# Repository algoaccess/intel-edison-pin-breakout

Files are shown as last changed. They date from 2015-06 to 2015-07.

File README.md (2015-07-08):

# intel-edison-pin-breakout
Pin breakout of the Intel Edison Hirose connector to through-hole pin headers for prototyping.

##PCB Design software and addons used

1. Eagle 7.3.0: I use Standard but Light should still be able to open/modify the files.
2. Intel Edison library by [Sparkfun](https://github.com/sparkfun/Sparkfun_Blocks_Template) (in repo as Edison.lbr)

##Images

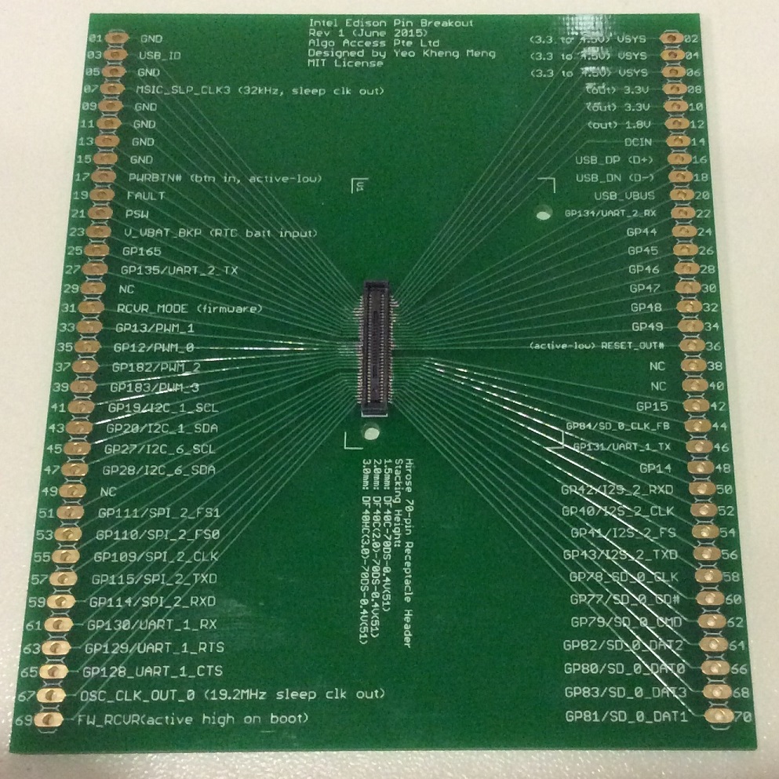
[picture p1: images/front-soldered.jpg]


This has the 1.5mm Hirose connector which I hand soldered.

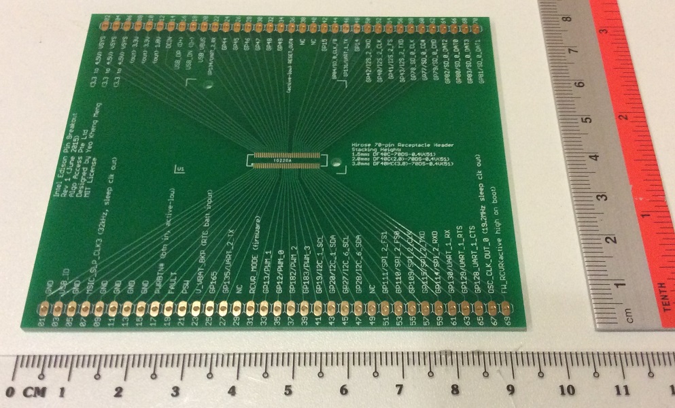
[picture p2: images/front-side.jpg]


The smallest I can make this board to still allow the function of each pin to be silkscreened.

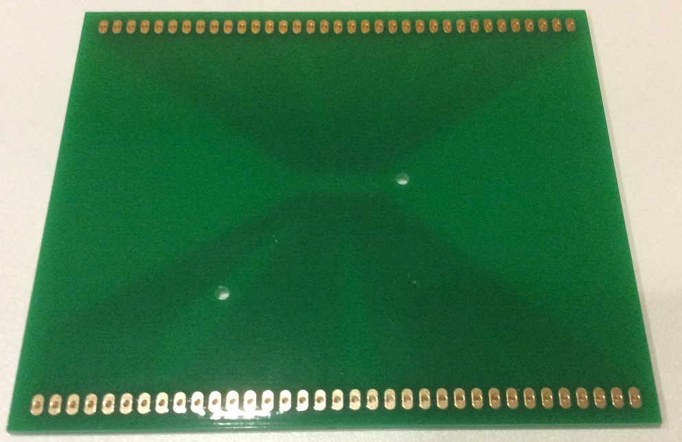
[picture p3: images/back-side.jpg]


2-layer board so you can solder your pin headers on top or below the board.

##Schematic drawings
Images are exported from Eagle at 600dpi.

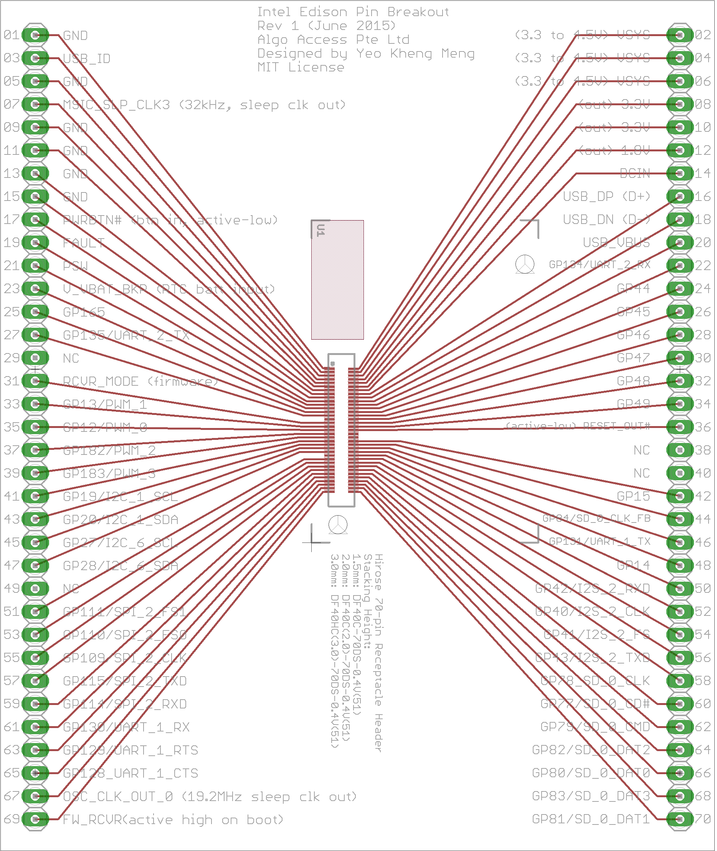
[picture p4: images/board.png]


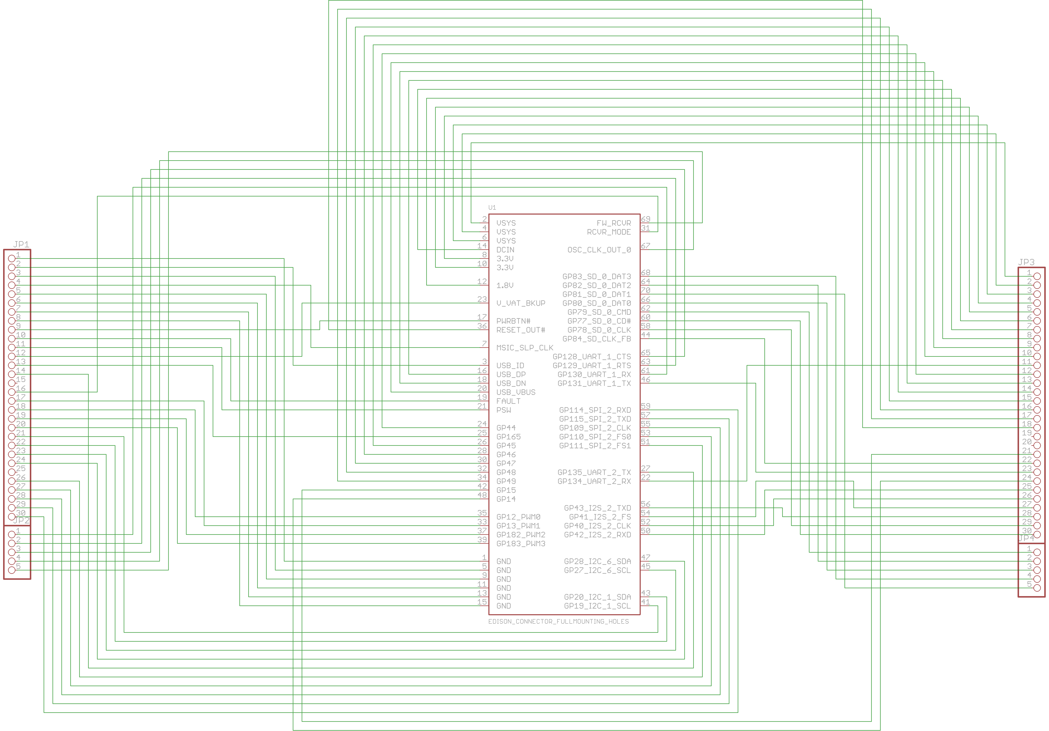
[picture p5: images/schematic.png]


##Parts required

1) Hirose 70-pin DF40 Series Receptacle Connector. Such as the following taken from [Intel's website](http://www.intel.com/support/edison/sb/CS-035260.htm).

| Hirose part number | Stacking height | Digi-key part number | Mouser part number |
|---|---|---|---|
| DF40C-70DS-0.4V(51) | 1.5 mm | H11631TR-ND, [H11631CT-ND](http://www.digikey.sg/product-detail/en/DF40C-70DS-0.4V%2851%29/H11631CT-ND/1969510), H11631DKR-ND | 798-DF40C70DS04V51 |
| DF40C(2.0)-70DS-0.4V(51)  | 2.0 mm | H11908TR-ND, H11908CT-ND, H11908DKR-ND | 798-DF40C2070DS04V51 |
| DF40HC(3.0)-70DS-0.4V(51) | 3.0 mm | n/a | |

I suggest the 1.5mm height header so the Intel Edison can be laid flat on the board without stressing the connectors between them.

2) 2x 35-pin through-hole pin-headers

I used a 36-pin header like [this](http://www.digikey.sg/product-detail/en/PBC36SAAN/S1011E-36-ND/859621) and broke away the last pin.

##PCB fabrication

PCB fabrication is currently done by [Seeedstudio](https://www.seeedstudio.com/service/index.php?r=pcb) based on the following settings. Remember to consult the [order submission guidelines](http://support.seeedstudio.com/knowledgebase/articles/422482-fusion-pcb-order-submission-guidelines) before submitting. Use the provided Gerber generator to produce the Gerber files.

Seeedstudio requires the following gerber files to be zipped up for submission:

1. Top Layer: pcbname.GTL
2. Top Solder Mask: pcbname.GTS
3. Top Silkscreen: pcbname.GTO
4. Bottom Layer: pcbname.GBL
5. Bottom Solder Mask: pcbname.GBS
6. Bottom silkscreen: pcbname.GBO
7. Board Outline:pcbname.GML/GKO
8. Drills: pcbname.TXT
9. Inner Layer: pcbname.GL2(for 4 layer)
10. Inner Layer: pcbname.GL3(for 4 layer)

The zip file has been uploaded to the Releases section.

###My Fabrication Settings: 

1. Layer: 2
2. PCB Dimension: 10cm Max * 10cm Max
3. PCB Thickness: 1.6mm
4. PCB Qty: 10
5. PCB Color: Green
6. Surface Finish: ENIG (due to fine pitch of the pins)
7. Copper weight: 1oz
8. Panalized PCBs: 1
9. Expedited Option: No

##References
1. [Intel Edison Module Hardware guide](http://www.intel.com/support/edison/sb/CS-035274.htm)
2. [Sparkfun Intel Edison layout diagram](https://cdn.sparkfun.com/assets/learn_tutorials/3/2/2/edison-pinout.pdf)

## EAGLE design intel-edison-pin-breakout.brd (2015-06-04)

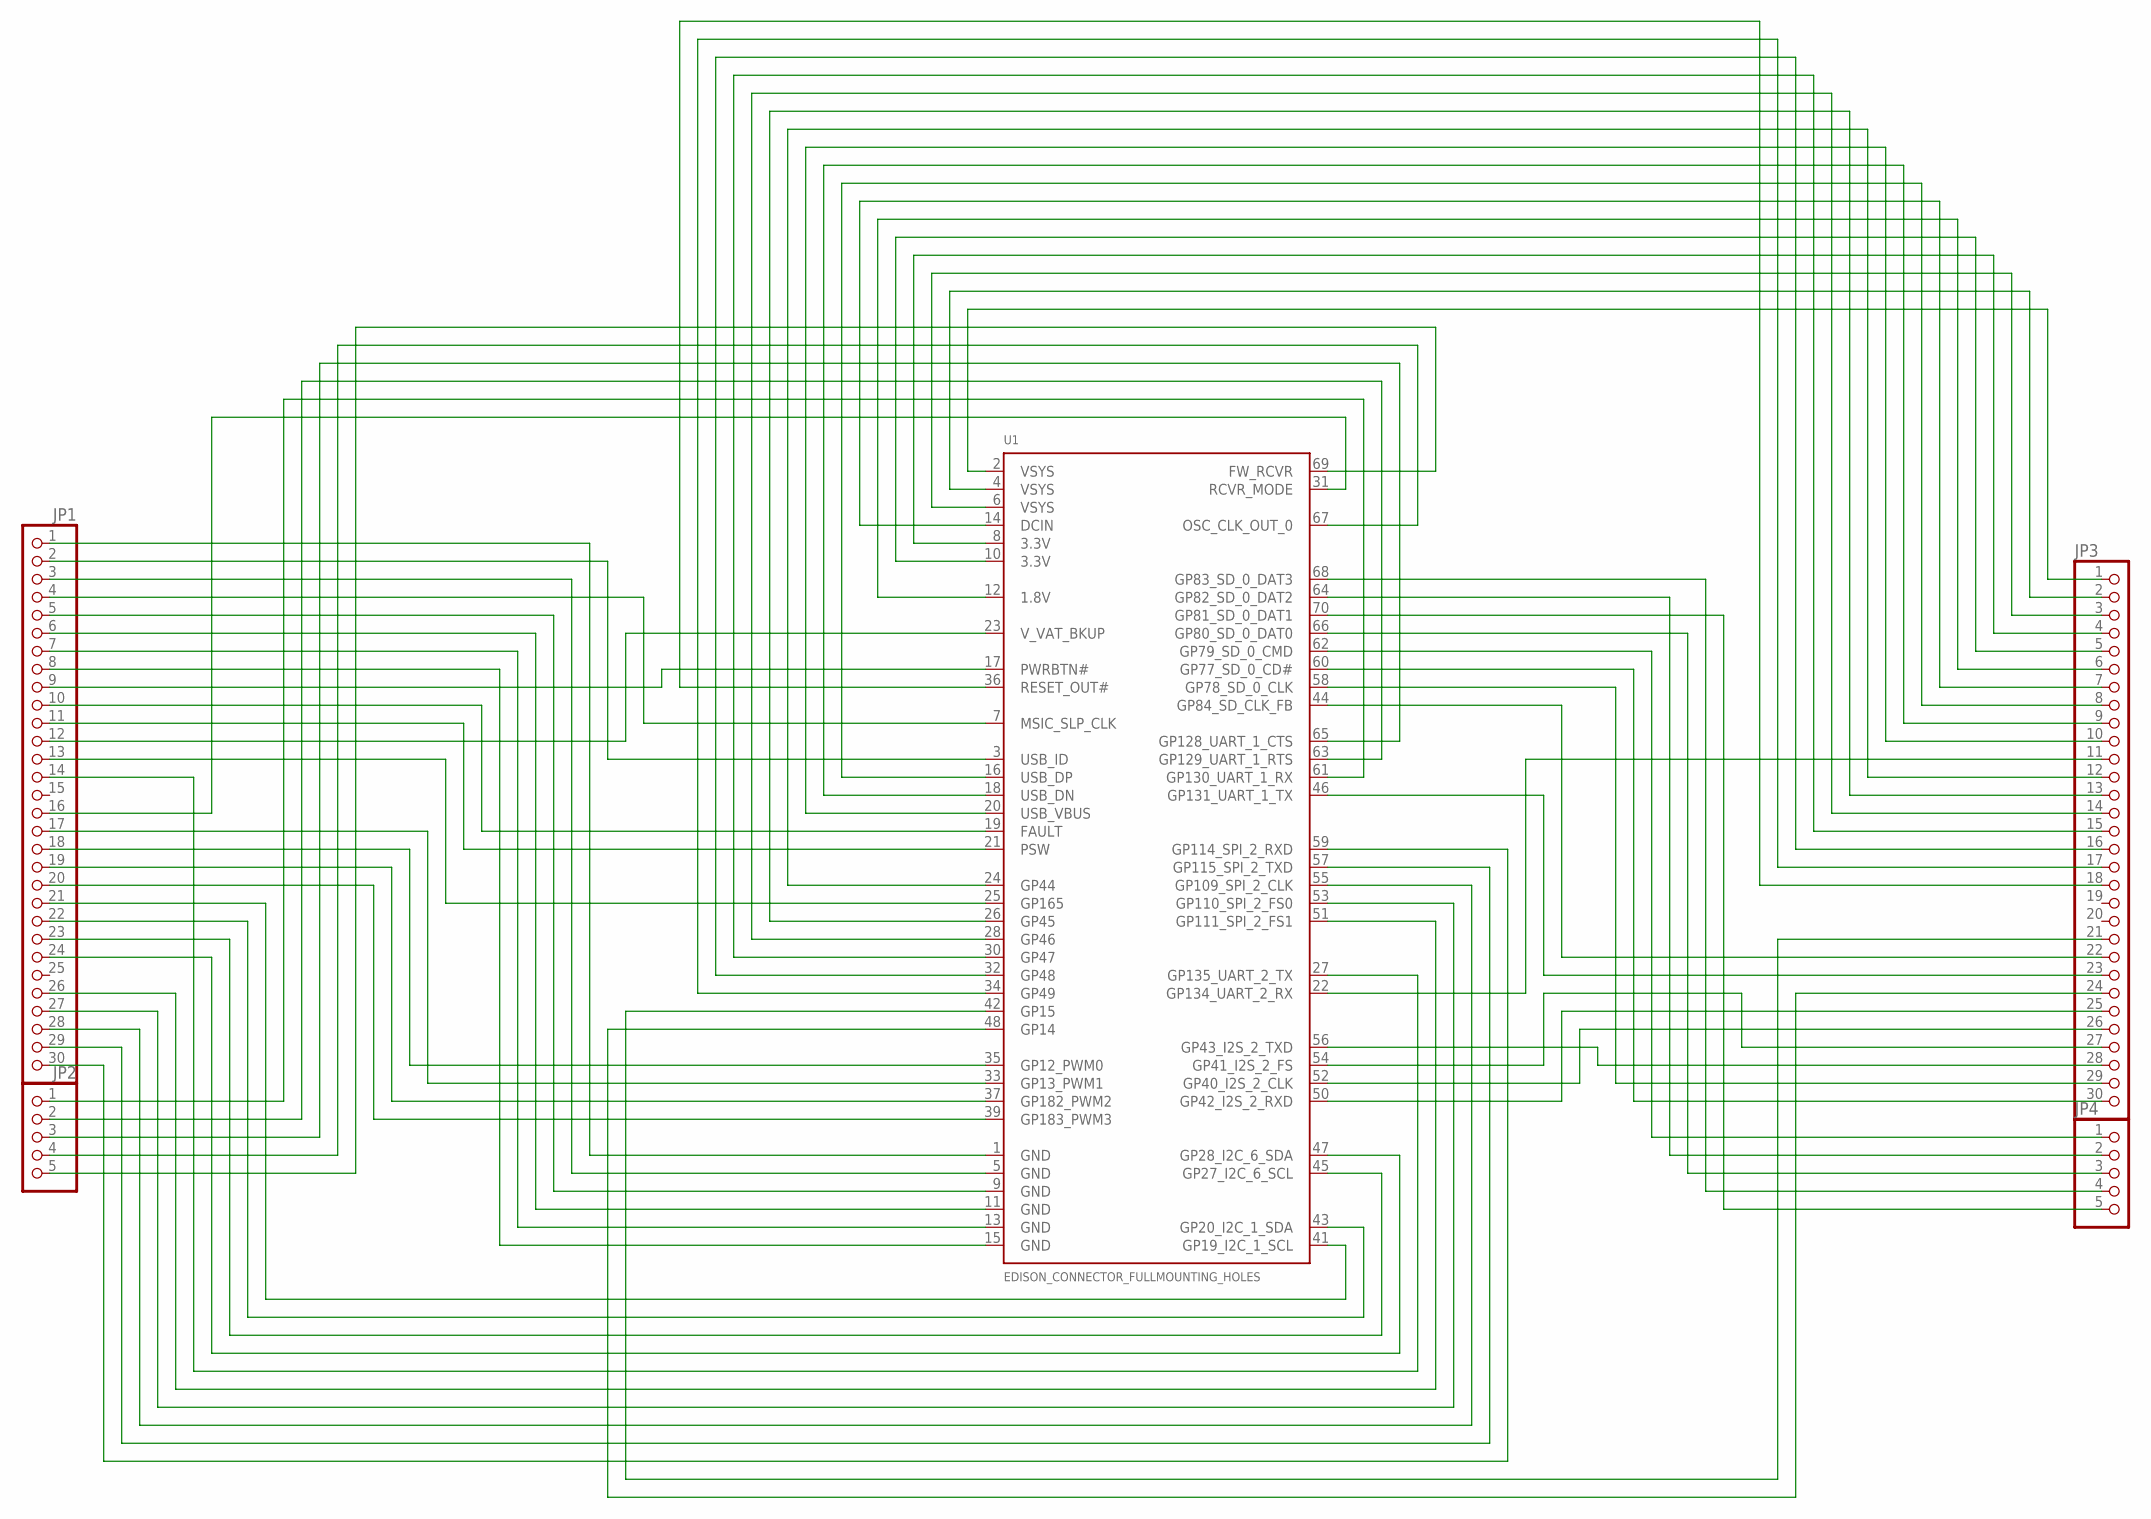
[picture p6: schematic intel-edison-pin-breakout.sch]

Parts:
JP1, JP3: PINHD-1X30; 1X30
JP2, JP4: PINHD-1X5; 1X05
U1: EDISON_CONNECTOR_FULLMOUNTING_HOLES; EDISON_DAUGHTER

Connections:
unnamed: JP1.1, U1.1 (GND)
unnamed: JP1.2, U1.3 (USB_ID)
unnamed: JP1.3, U1.5 (GND)
unnamed: JP1.4, U1.7 (MSIC_SLP_CLK)
unnamed: JP1.5, U1.9 (GND)
unnamed: JP1.6, U1.11 (GND)
unnamed: JP1.7, U1.13 (GND)
unnamed: JP1.8, U1.15 (GND)
unnamed: JP1.9, U1.17 (PWRBTN#)
unnamed: JP1.10, U1.19 (FAULT)
unnamed: JP1.11, U1.21 (PSW)
unnamed: JP1.12, U1.23 (V_VAT_BKUP)
unnamed: JP1.13, U1.25 (GP165)
unnamed: JP1.17, U1.33 (GP13_PWM1)
unnamed: JP1.16, U1.31 (RCVR_MODE)
unnamed: JP1.18, U1.35 (GP12_PWM0)
unnamed: JP1.19, U1.37 (GP182_PWM2)
unnamed: JP1.20, U1.39 (GP183_PWM3)
unnamed: JP1.21, U1.41 (GP19_I2C_1_SCL)
unnamed: JP1.22, U1.43 (GP20_I2C_1_SDA)
unnamed: JP1.23, U1.45 (GP27_I2C_6_SCL)
unnamed: JP1.24, U1.47 (GP28_I2C_6_SDA)
unnamed: JP1.26, U1.51 (GP111_SPI_2_FS1)
unnamed: JP1.27, U1.53 (GP110_SPI_2_FS0)
unnamed: JP1.28, U1.55 (GP109_SPI_2_CLK)
unnamed: JP1.29, U1.57 (GP115_SPI_2_TXD)
unnamed: JP1.30, U1.59 (GP114_SPI_2_RXD)
unnamed: JP1.14, U1.27 (GP135_UART_2_TX)
unnamed: JP2.1, U1.61 (GP130_UART_1_RX)
unnamed: JP2.2, U1.63 (GP129_UART_1_RTS)
unnamed: JP2.3, U1.65 (GP128_UART_1_CTS)
unnamed: JP2.4, U1.67 (OSC_CLK_OUT_0)
unnamed: JP2.5, U1.69 (FW_RCVR)
unnamed: JP3.1, U1.2 (VSYS)
unnamed: JP3.2, U1.4 (VSYS)
unnamed: JP3.3, U1.6 (VSYS)
unnamed: JP3.4, U1.8 (3.3V)
unnamed: JP3.5, U1.10 (3.3V)
unnamed: JP3.6, U1.12 (1.8V)
unnamed: JP3.7, U1.14 (DCIN)
unnamed: JP3.8, U1.16 (USB_DP)
unnamed: JP3.9, U1.18 (USB_DN)
unnamed: JP3.10, U1.20 (USB_VBUS)
unnamed: JP3.18, U1.36 (RESET_OUT#)
unnamed: JP3.12, U1.24 (GP44)
unnamed: JP3.13, U1.26 (GP45)
unnamed: JP3.14, U1.28 (GP46)
unnamed: JP3.15, U1.30 (GP47)
unnamed: JP3.16, U1.32 (GP48)
unnamed: JP3.17, U1.34 (GP49)
unnamed: JP3.11, U1.22 (GP134_UART_2_RX)
unnamed: JP3.21, U1.42 (GP15)
unnamed: JP4.5, U1.70 (GP81_SD_0_DAT1)
unnamed: JP4.4, U1.68 (GP83_SD_0_DAT3)
unnamed: JP3.24, U1.48 (GP14)
unnamed: JP4.3, U1.66 (GP80_SD_0_DAT0)
unnamed: JP4.2, U1.64 (GP82_SD_0_DAT2)
unnamed: JP4.1, U1.62 (GP79_SD_0_CMD)
unnamed: JP3.30, U1.60 (GP77_SD_0_CD#)
unnamed: JP3.29, U1.58 (GP78_SD_0_CLK)
unnamed: JP3.27, U1.54 (GP41_I2S_2_FS)
unnamed: JP3.23, U1.46 (GP131_UART_1_TX)
unnamed: JP3.26, U1.52 (GP40_I2S_2_CLK)
unnamed: JP3.25, U1.50 (GP42_I2S_2_RXD)
unnamed: JP3.22, U1.44 (GP84_SD_CLK_FB)
unnamed: JP3.28, U1.56 (GP43_I2S_2_TXD)

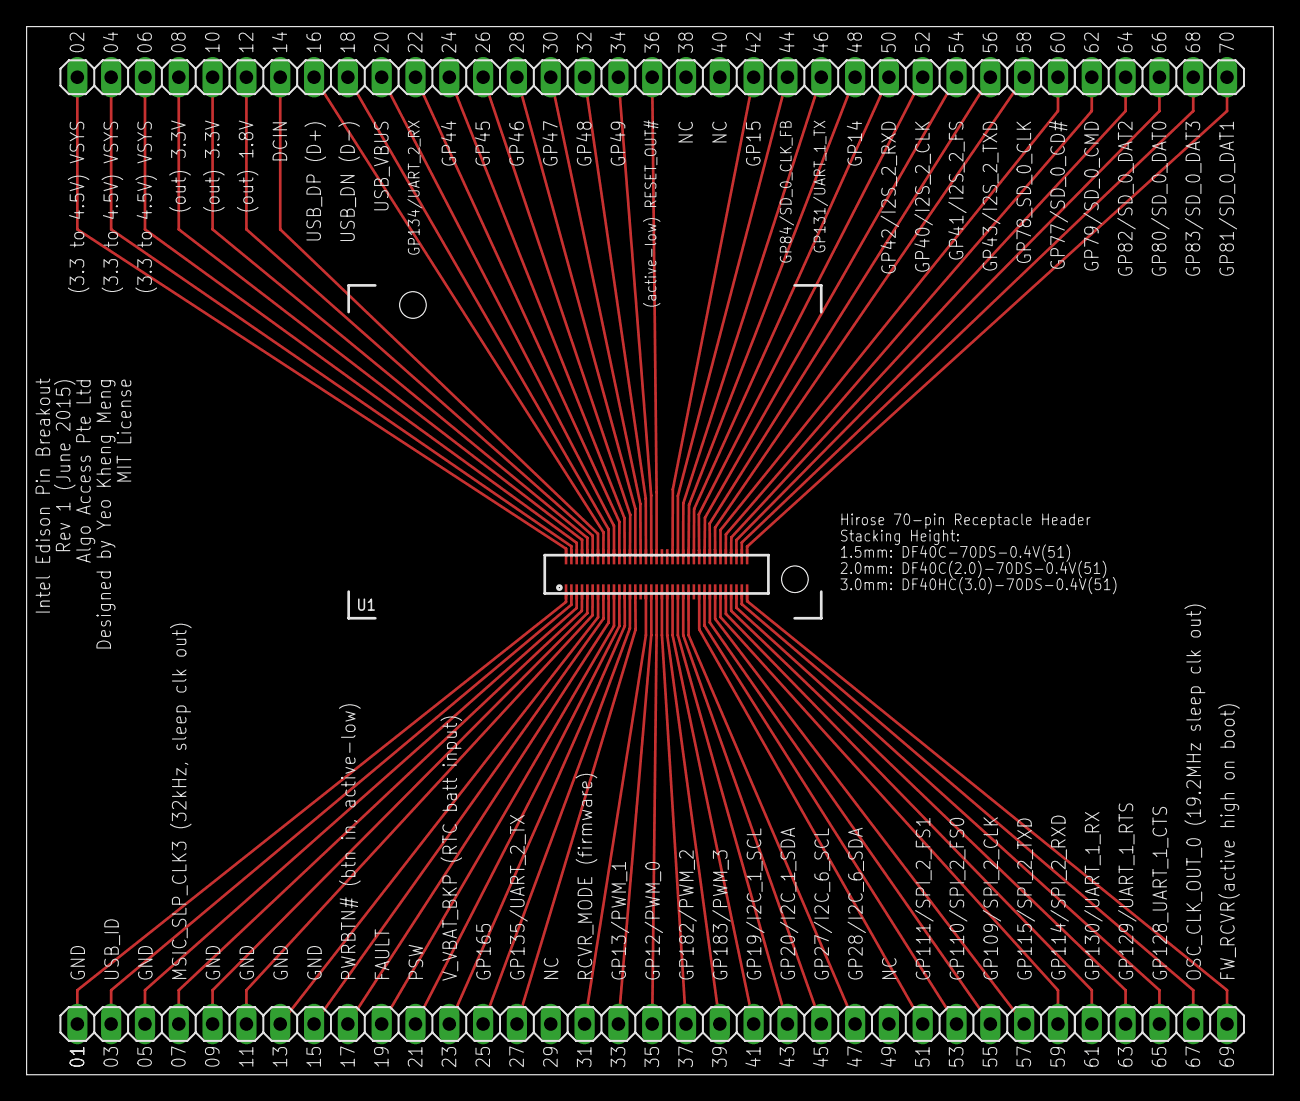
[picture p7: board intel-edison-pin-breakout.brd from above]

Board: 2 copper layers, 93.7 x 78.7 mm, 5 parts (0 on the bottom side), 66 nets.

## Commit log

2015-06-03 board width
    [intel-edison-pin-breakout.brd]
2015-06-03 reduce board size
    [intel-edison-pin-breakout.brd]
2015-06-03 last 6 wires of each corner have edges
    [intel-edison-pin-breakout.brd]
2015-06-03 don't bend the last wire so much
    [intel-edison-pin-breakout.brd]
2015-06-03 put them closer
    [intel-edison-pin-breakout.brd]
2015-06-03 all pins fit on smaller board
    [intel-edison-pin-breakout.brd]
2015-06-03 pin numbering
    [intel-edison-pin-breakout.brd]
2015-06-03 a few labels
    [intel-edison-pin-breakout.brd]
2015-06-04 dummy labels
    [intel-edison-pin-breakout.brd]
2015-06-04 labels in right orientation
    [intel-edison-pin-breakout.brd]
2015-06-04 wire movements and some labels
    [intel-edison-pin-breakout.brd]
2015-06-04 bottom labels
    [intel-edison-pin-breakout.brd]
2015-06-04 pin names
    [intel-edison-pin-breakout.brd]
2015-06-04 label changes
    [intel-edison-pin-breakout.brd]
2015-06-04 mint license
    [intel-edison-pin-breakout.brd]
2015-06-04 hirose connector label
    [intel-edison-pin-breakout.brd]
2015-06-04 rotate board
2015-06-04 2 layers for PCB Fab

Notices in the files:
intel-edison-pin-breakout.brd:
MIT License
